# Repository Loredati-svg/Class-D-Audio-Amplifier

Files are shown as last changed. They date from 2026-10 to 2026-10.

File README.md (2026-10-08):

<h1 align="center">🔊 Class-D Stereo Audio Amplifier</h1>

<p align="center">
  
  
  
  
</p>

An open-source stereo **Class-D** audio amplifier with a **USB-C digital input**, analog **bass / treble tone control** and a **volume knob**, built around the Texas Instruments **TPA3116D2** and designed in **KiCad 10.0**.

Plug a phone or a PC into the USB-C port: the board shows up as a standard USB sound card (no drivers needed) and drives a pair of passive bookshelf speakers (4–8 Ω) from a single **24 V DC** supply.

---

> 🛠️ **Project Status: Active Development (v1)**
> The v1 schematic is being finalized; PCB layout comes next. Suggestions and feedback are welcome!

> 📶 **About Bluetooth**
> Bluetooth support is currently **on hold**. It will be reintegrated in a future hardware revision, once the v1 board (USB-C, without Bluetooth) has been built and validated.

---

## 📋 Table of Contents
- [Technical Specifications](#-technical-specifications)
- [Signal Chain](#-signal-chain)
- [Circuit Blocks](#-circuit-blocks)
- [Gain Structure](#-gain-structure)
- [Repository Structure](#-repository-structure)
- [Manufacturing](#-manufacturing)
- [Roadmap](#-roadmap)
- [License](#-license)

---

## ⚡ Technical Specifications

| Parameter | Value |
| :--- | :--- |
| **Supply voltage** | 24 V DC (3–5 A recommended), 5.5 × 2.1 mm barrel jack |
| **Audio input** | USB-C (USB 2.0 Full-Speed, USB Audio Class 1.0), 16-bit / up to 48 kHz |
| **DAC** | Texas Instruments **PCM2704C** |
| **Tone control** | Active Baxandall – bass and treble, about ±12 dB |
| **Amplifier IC** | Texas Instruments **TPA3116D2** (stereo BTL, Master mode, 26 dB) |
| **Output power** | ≈ 2 × 40 W into 4 Ω (clean), up to 2 × 50 W at 10 % THD |
| **Speaker load** | 4–8 Ω passive speakers |
| **Speaker outputs** | Phoenix Contact MKDS 1,5/2-5,08 screw terminals |
| **Controls** | Bass, Treble, Volume (dual-gang potentiometers) |
| **PCB** | 2 layers, FR-4, 1.6 mm, 1 oz copper |

---

## 🔗 Signal Chain

```mermaid
flowchart LR
    A[Phone / PC<br/>USB-C] --> B[PCM2704C<br/>USB Audio DAC]
    B --> C[Baxandall tone control<br/>OPA1678 · Bass / Treble]
    C --> D[Volume<br/>dual log pot]
    D --> E[TPA3116D2<br/>26 dB]
    E --> F[LC filter]
    F --> G[Speakers<br/>4–8 Ω]
```

---

## 🧩 Circuit Blocks

### USB-C input and DAC
- USB 2.0 Type-C receptacle with **5.1 kΩ** pull-downs on CC1/CC2 (device / UFP), so the phone acts as host and supplies VBUS
- **USBLC6-2SC6** ESD protection on D+, D− and VBUS
- **PCM2704C** bus-powered from VBUS: USB Audio Class 1.0, driverless on Android, iOS, Windows, macOS and Linux
- 12 MHz crystal, 22 Ω series resistors and 1.5 kΩ pull-up on D+
- AC-coupled line outputs (10 µF + 47 kΩ)

### Tone control
- Active **Baxandall** network (one per channel) around a TI **OPA1678** (dual, rail-to-rail output, low noise)
- **Bass:** shelf centred around ≈ 50 Hz, tuned for deep 808-style bass
- **Treble:** ≈ 8–10 kHz, mainly to tame harsh highs
- Unity gain with the knobs centred

### Volume
- Dual-gang **A10K** logarithmic potentiometer
- Placed **after** the tone stage, so it also attenuates op-amp noise at low listening levels

### Analog supply
- **L78L12** LDO: 24 V → 12 V for the op-amp
- **VREF = 6 V** virtual ground (100 kΩ / 100 kΩ divider + 10 µF) for single-supply operation

### Power amplifier (TPA3116D2)
- **Gain / mode:** 20 kΩ to GND and 100 kΩ to GVDD on `GAIN/SLV` → Master mode, 26 dB, 30 kΩ input impedance
- **Inputs:** single-ended, negative inputs AC-grounded through capacitors matching the positive ones (3.3 µF)
- **Modulation:** BD mode, 400 kHz switching, no power limit
- **PVCC decoupling:** 1 nF + 100 nF ceramic + 220 µF + 470 µF low-ESR bulk on each side of the IC
- **Output filter:** 10 µH / 680 nF LC filter + RC snubbers for EMI
- **Protection:** `FAULTZ` tied to `SDZ` for automatic recovery after a fault
- **Thermal:** the DAD package has its **PowerPAD on top**, so a heatsink must be mounted on the IC

### Anti-pop
- The PCM2704C `SSPND` signal (high when USB audio is active) drives a **2N7002** inverter on the TPA3116D2 `MUTE` pin
- RC network on `MUTE` (100 kΩ + 4.7 µF): unmute ≈ 1 s after the DAC becomes active, mute within ≈ 0.1 s when the phone is unplugged, slew rate within datasheet limits
- RC delay on `SDZ` (100 kΩ + 10 µF) keeps the amplifier in shutdown while the supplies settle at power-up

### Front-panel controls

| Knob | Part | Function |
| :--- | :--- | :--- |
| **Bass** | B100K dual-gang (RV1) | Low-frequency boost / cut |
| **Treble** | B100K dual-gang (RV2) | High-frequency boost / cut |
| **Volume** | A10K dual-gang (RV3) | Master volume |

---

## 📊 Gain Structure

The gain chain is chosen so that **full volume reaches maximum clean power without clipping**, and the op-amp keeps headroom even with the bass knob fully up.

| Stage | Gain | Level at full scale |
| :--- | :--- | :--- |
| PCM2704C output | – | 0.64 Vrms |
| Tone control (flat) | ×1 (0 dB) | 0.64 Vrms |
| Volume (max) | ×1 | 0.64 Vrms |
| TPA3116D2 | ×20 (26 dB) | ≈ 12.8 Vrms → ≈ 40 W into 4 Ω |

Worst case (full-scale track, +12 dB bass boost): the OPA1678 output swings ≈ 7.2 Vpp around 6 V, well inside its 12 V rail-to-rail range. If the amplifier clips, it happens **after** the volume knob, so turning the volume down removes it.

---

## 📁 Repository Structure

```
Class-D-Bluetooth-5.0-Stereo-Audio-Amplifier/
├── KiCad_Project/
│   ├── Audio_Amp_v1/          # v1 – USB-C DAC + tone control (schematic + PCB)
│   └── Fabrication_files/     # Gerber, drill, BOM and CPL (coming soon)
├── libs/                           # Project-specific symbols, footprints and 3D models
└── README.md
```

### Schematic sheets

| Sheet | Content |
| :--- | :--- |
| `USB_DAC` | USB-C, ESD protection, PCM2704C, crystal, L78L12, power input, speaker terminals, anti-pop driver |
| `Tone_Volume_control` | OPA1678, VREF, Baxandall networks (L/R), volume potentiometer |
| `Power_Amplifier` | TPA3116D2, gain setting, PVCC decoupling, LC output filter, EMI snubbers |

---

## 🏭 Manufacturing

The board is designed to be manufactured by **JLCPCB** and assembled by hand (stencil + hot plate / hot air for SMD parts, soldering iron for through-hole parts).

| Option | Value |
| :--- | :--- |
| Layers | 2 |
| Thickness | 1.6 mm |
| Copper | 1 oz |
| Gerber export | Protel extensions, no X2 attributes |
| Drill | Excellon, mm, PTH + NPTH merged |
| Stencil | Top side only |

---

## 🗺️ Roadmap

**v1 – USB-C DAC (current)**
- [x] USB-C input and PCM2704C DAC
- [x] Baxandall tone control and volume
- [x] TPA3116D2 power stage
- [x] Anti-pop circuit
- [ ] ERC and schematic review
- [ ] Tone control AC simulation (ngspice)
- [ ] PCB layout and DRC
- [ ] Fabrication, assembly and bring-up
- [ ] Measurements (frequency response, THD+N, noise)
- [ ] Enclosure and front panel

**Future**
- [ ] Bluetooth input (reintegrated once v1 is validated)

---

## 📜 License

This hardware project is released under the **CERN Open Hardware Licence Permissive v2 ([CERN-OHL-P v2](https://ohwr.org/cernohl))**.

<p align="center">Designed by <b>LOREDATI Circuits</b></p>

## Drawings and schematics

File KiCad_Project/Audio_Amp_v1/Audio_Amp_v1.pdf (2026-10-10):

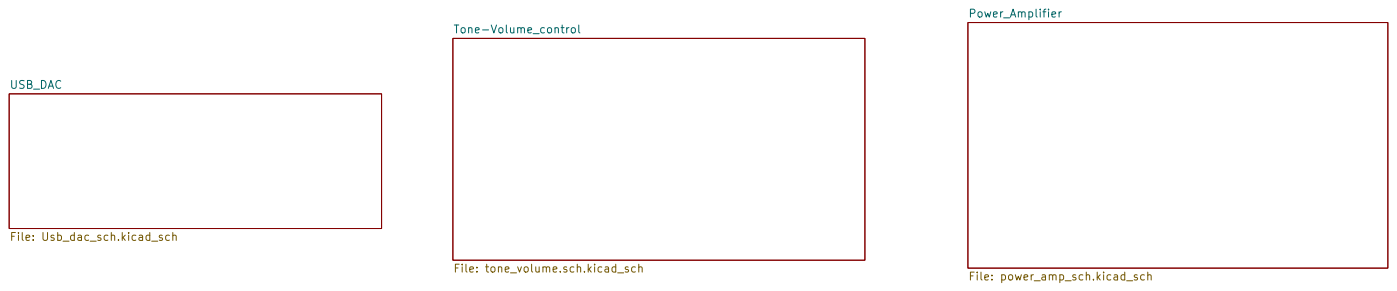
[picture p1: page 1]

Sheet: /
File: Audio_Amp_v1.kicad_sch
Title: Class-D Stereo Amplifier – USB-C v1

Size: A4 | Rev: v1
KiCad E.D.A. 10.0.5 | Id: 1/4

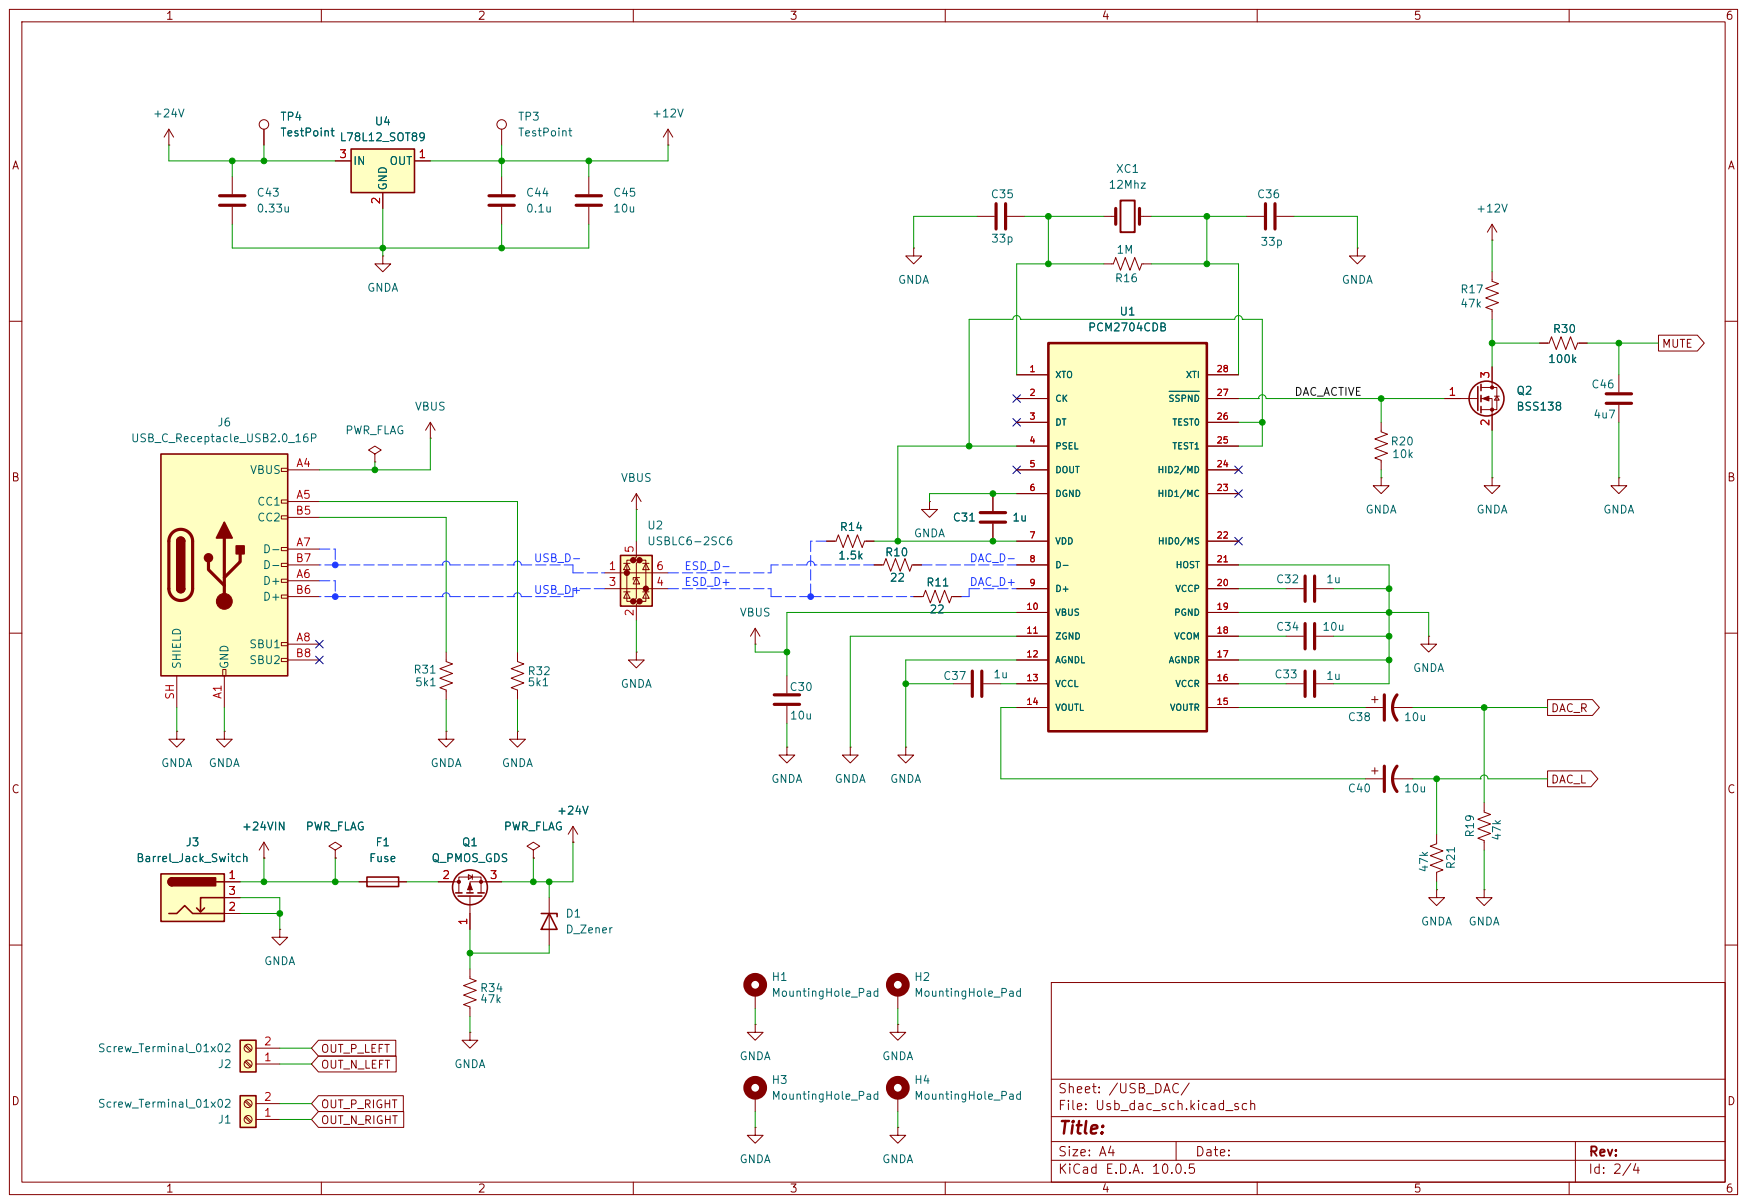
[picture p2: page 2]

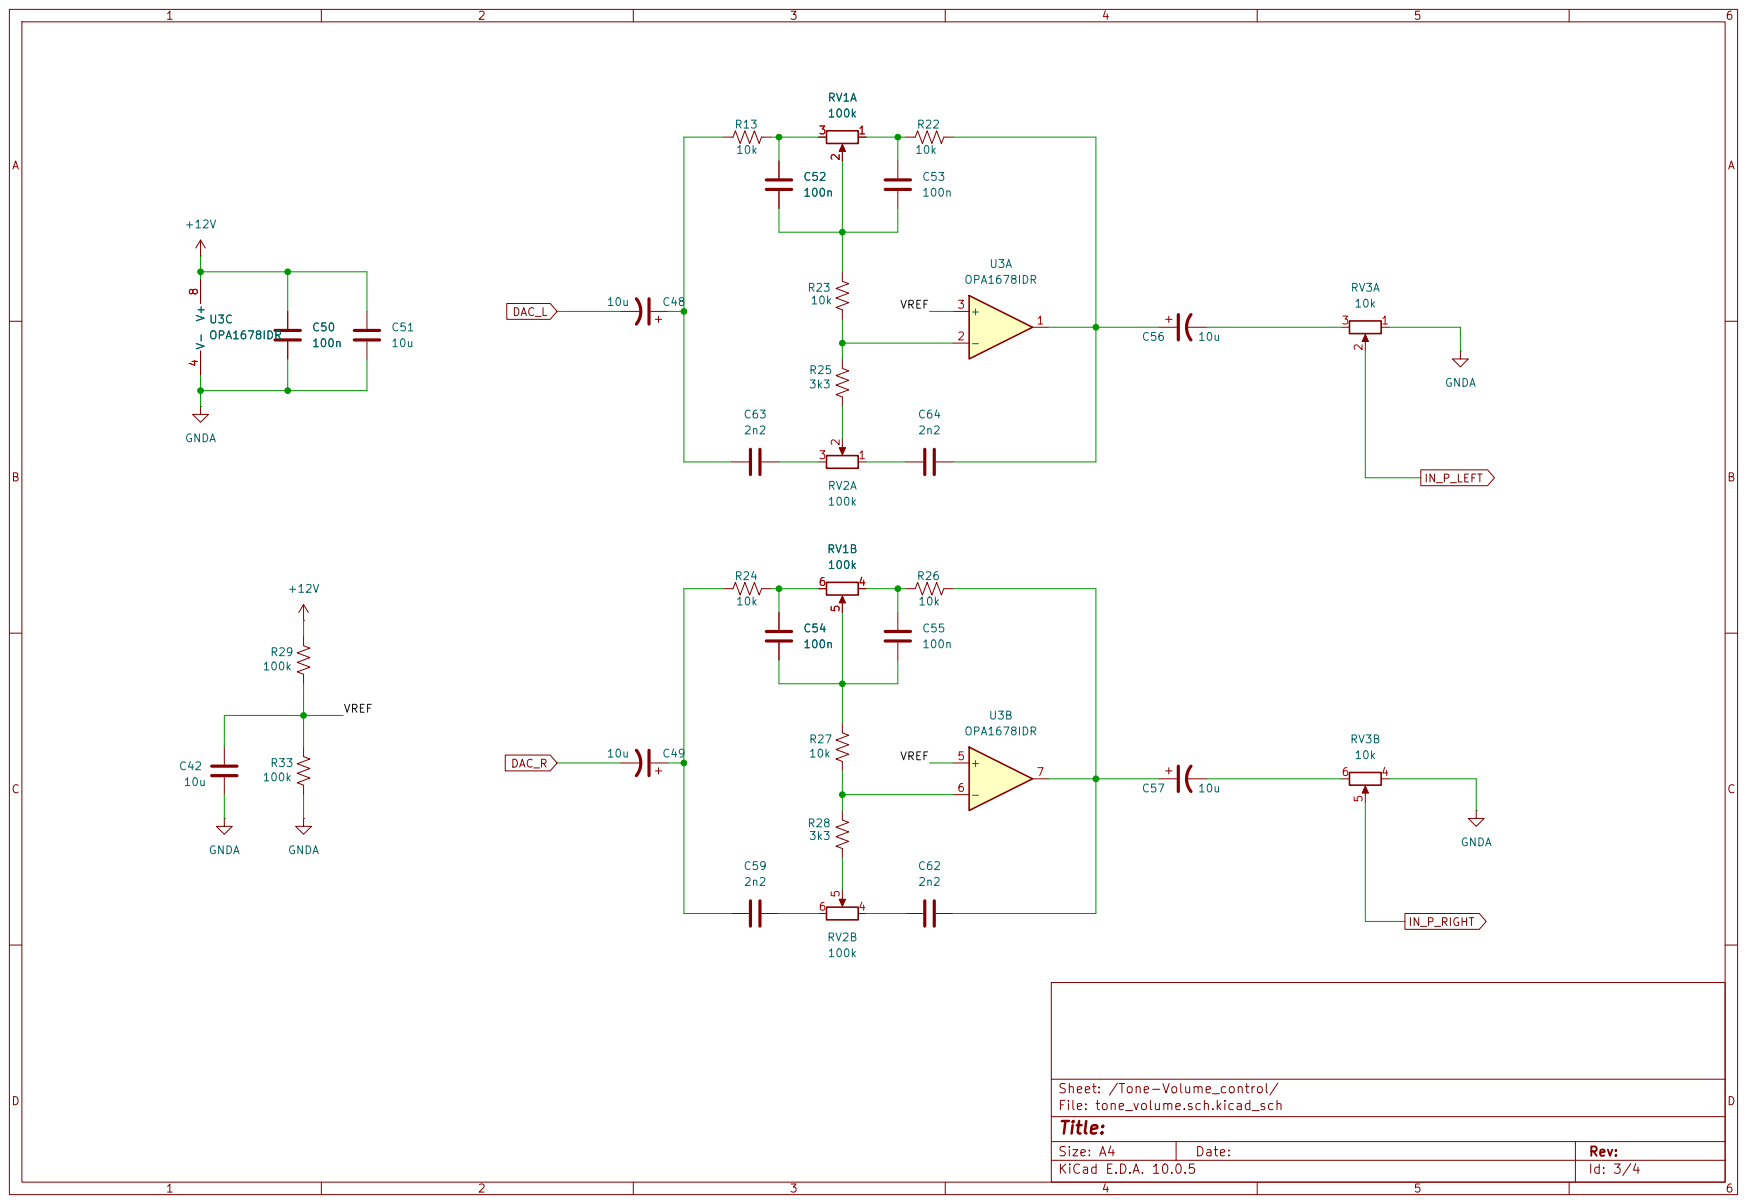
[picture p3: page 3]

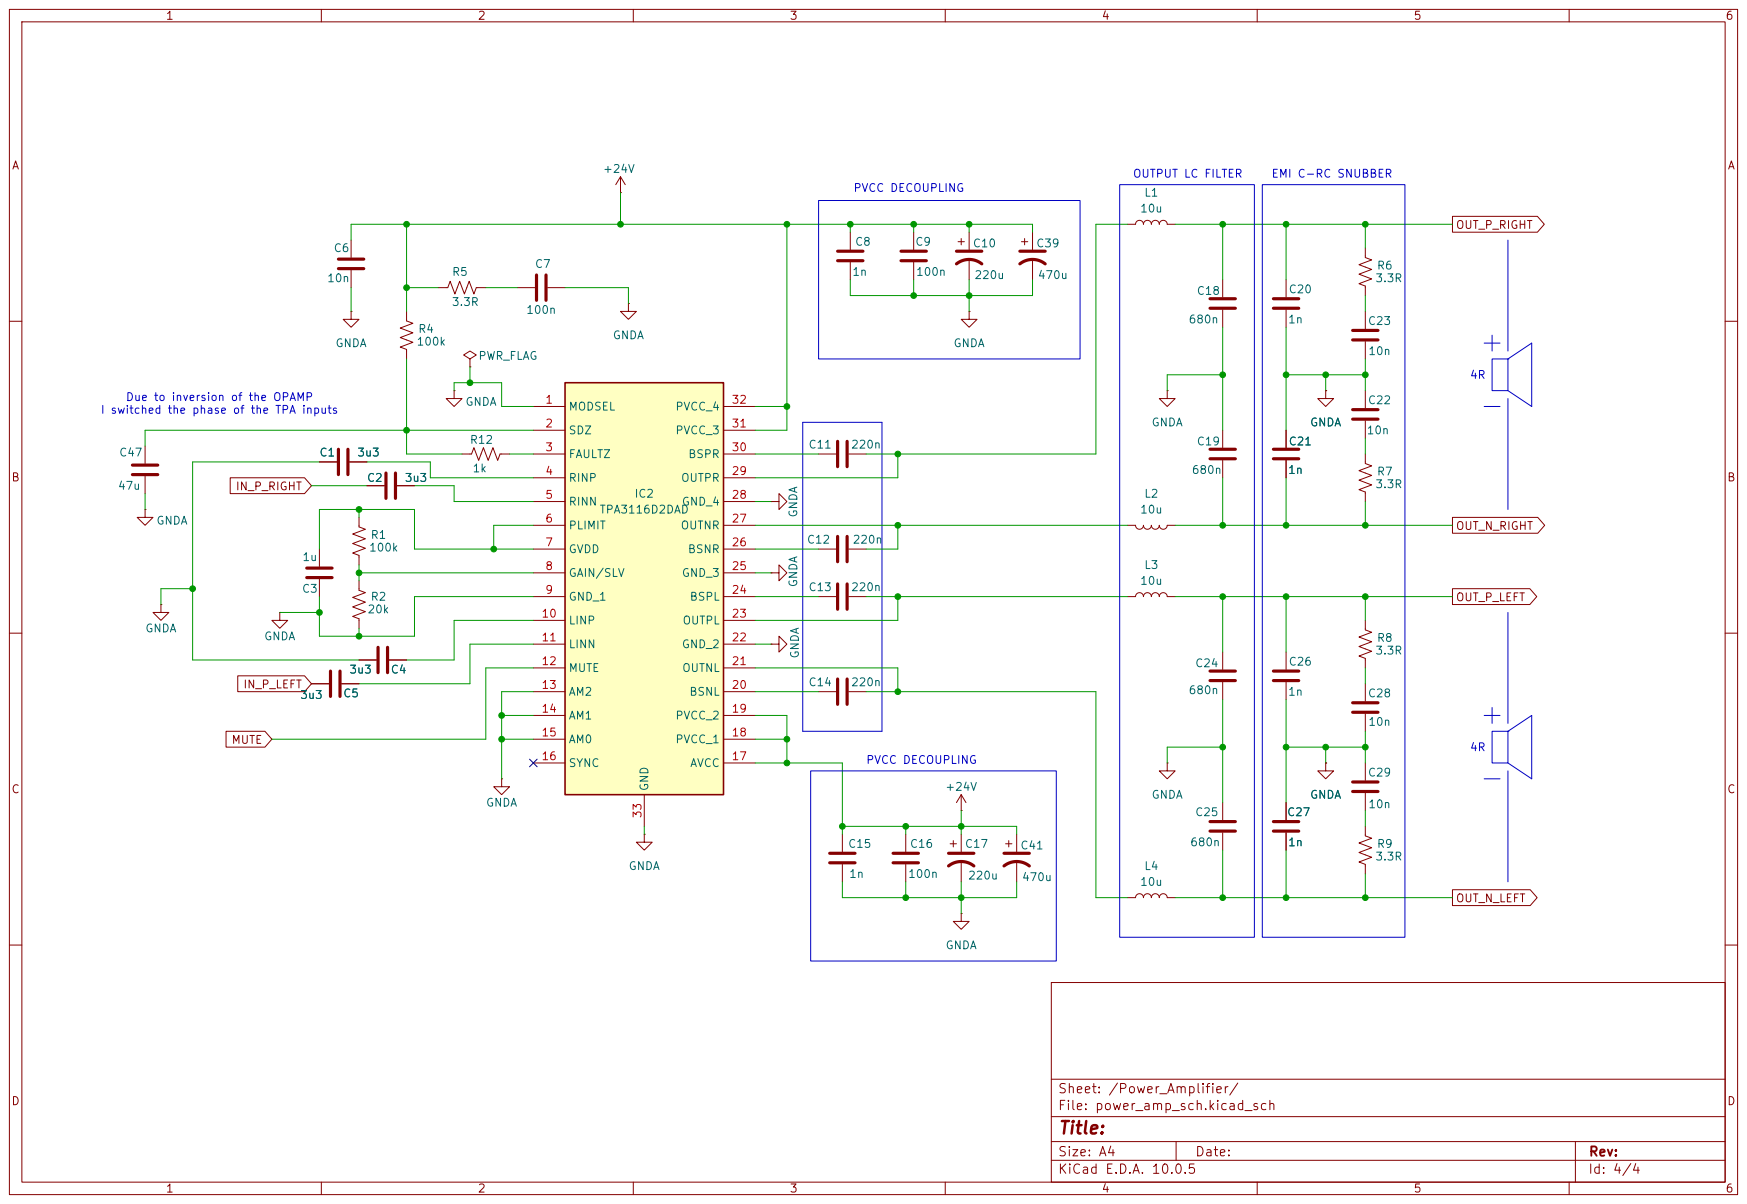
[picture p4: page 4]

Due to inversion of the OPAMP

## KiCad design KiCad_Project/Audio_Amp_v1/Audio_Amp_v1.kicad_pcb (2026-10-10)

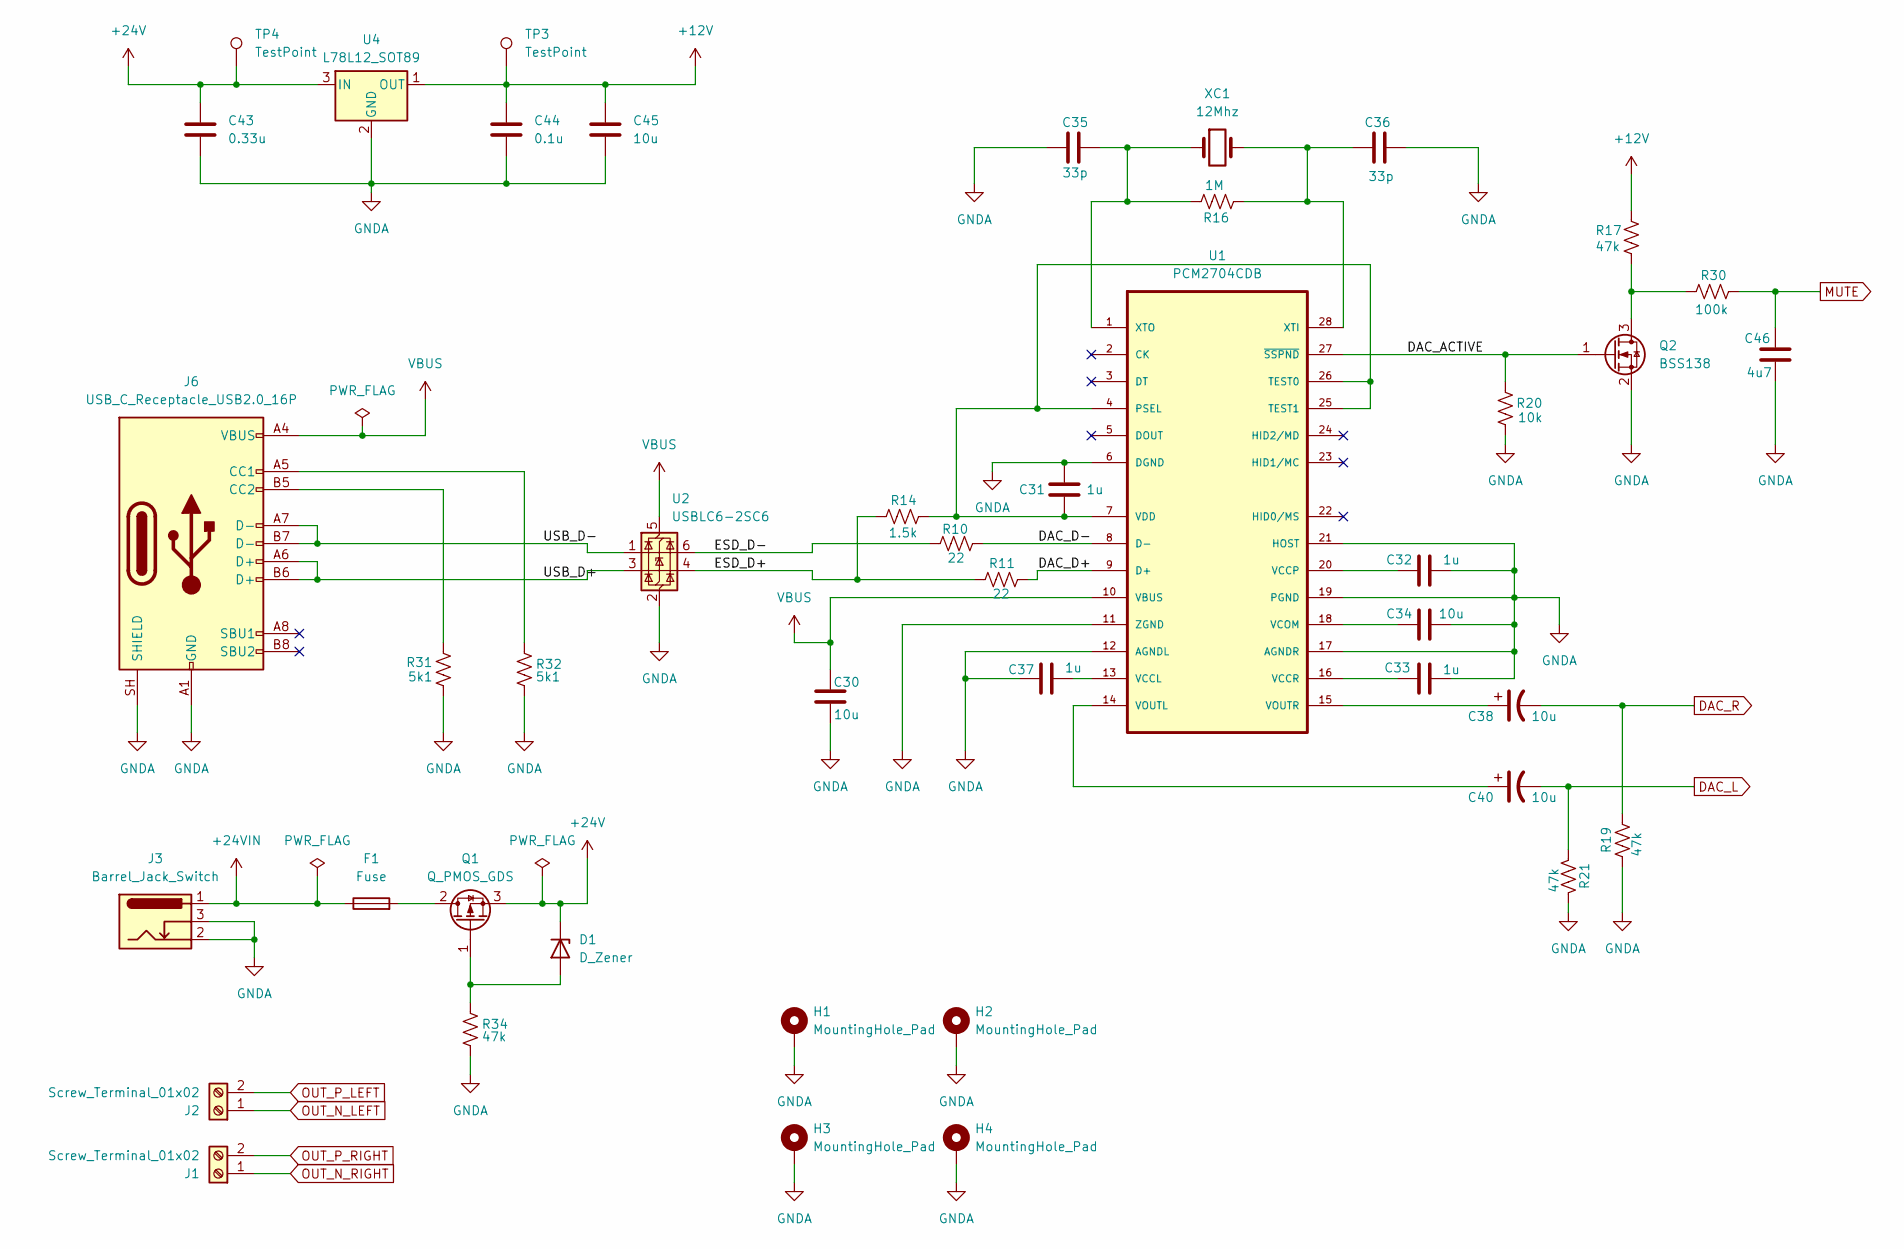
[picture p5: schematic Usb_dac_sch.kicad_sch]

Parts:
C30, C45: 10u; C_0805_2012Metric
C31: 1u; C_0603_1608Metric; LCSC C5199872
C32, C33, C37: 1u; C_0603_1608Metric
C34: 10u; C_0603_1608Metric
C35, C36: 33p; C_0603_1608Metric
C38, C40: 10u; CP_Elec_4x5.8; LCSC C116211
C43: 0.33u; C_0805
C44: 0.1u; C_0603_1608Metric
C46: 4u7; C_0805_2012Metric
D1: D_Zener; D_SOD-123
F1: Fuse; Fuse_2920_7451Metric_Pad2.10x5.45mm_HandSolder
H1, H2, H3, H4: MountingHole_Pad; MountingHole_3.2mm_M3_Pad_Via
J1, J2: Screw_Terminal_01x02; TerminalBlock_Phoenix_MKDS-1,5-2-5.08_1x02_P5.08mm_Horizont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
J3: Barrel_Jack_Switch; BarrelJack_CUI_PJ-102AH_Horizontal
J6: USB_C_Receptacle_USB2.0_16P; USB_C_Receptacle_GCT_USB4105-xx-A_16P_TopMnt_Horizontal
Q1: Q_PMOS_GDS; TO-252-2
Q2: BSS138; SOT-23
R10, R11: 22; R_0603_1608Metric; LCSC C25586
R14: 1.5k; R_0603_1608Metric; LCSC C25586
R16: 1M; R_0603_1608Metric
R17, R19, R21, R34: 47k; R_0603_1608Metric; LCSC C25586
R20: 10k; R_0603_1608Metric; LCSC C25586
R30: 100k; R_0603_1608Metric; LCSC C25586
R31, R32: 5k1; R_0603_1608Metric; LCSC C25586
TP3, TP4: TestPoint; TestPoint_Pad_D2.0mm
U1: PCM2704CDB; SOP65P780X200-28N
U2: USBLC6-2SC6; SOT-23-6
U4: L78L12_SOT89; SOT-89-3
XC1: 12Mhz; Crystal_SMD_HC49-SD; PARTNO ECS-120-20-5PX-TR

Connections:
+12V: C44.1, C45.1, R17.2, TP3.1 (1_1), U4.1 (OUT); also elsewhere on the board
+24V: C43.1, D1.1 (K), Q1.3 (S), TP4.1 (1_1), U4.3 (IN); also elsewhere on the board
+24VIN: F1.1, J3.1
/USB_DAC/DAC_ACTIVE: Q2.1 (G), R20.2, U1.27 (~SSPND)
/USB_DAC/DAC_D+: R11.2, U1.9 (D+)
/USB_DAC/DAC_D-: R10.2, U1.8 (D-)
/USB_DAC/ESD_D+: R11.1, R14.2, U2.4 (I/O2)
/USB_DAC/ESD_D-: R10.1, U2.6 (I/O1)
/USB_DAC/USB_D+: J6.A6 (D+), J6.B6 (D+), U2.3 (I/O2)
/USB_DAC/USB_D-: J6.A7 (D-), J6.B7 (D-), U2.1 (I/O1)
DAC_L: C40.2, R21.2; also elsewhere on the board
DAC_R: C38.2, R19.2; also elsewhere on the board
GNDA: C30.1, C31.2, C32.1, C33.1, C34.1, C35.1, C36.1, C37.2, C43.2, C44.2, C45.2, C46.2, H1.1 (1_1), H2.1 (1_1), H3.1 (1_1), H4.1 (1_1), J3.2, J3.3, J6.A1 (GND), J6.A12 (GND), J6.B1 (GND), J6.B12 (GND), J6.SH (SHIELD), Q2.2 (S), R19.1, R20.1, R21.1, R31.2, R32.2, R34.2, U1.6 (DGND), U1.11 (ZGND), U1.12 (AGNDL), U1.17 (AGNDR), U1.19 (PGND), U1.21 (HOST), U2.2 (GND), U4.2 (GND); also elsewhere on the board
MUTE: C46.1, R30.1; also elsewhere on the board
unnamed: D1.2 (A), Q1.1 (G), R34.1
unnamed: J6.A5 (CC1), R32.1
unnamed: J6.B5 (CC2), R31.1
unnamed: F1.2, Q1.2 (D)
unnamed: Q2.3 (D), R17.1, R30.2
unnamed: C31.1, R14.1, U1.4 (PSEL), U1.7 (VDD), U1.25 (TEST1), U1.26 (TEST0)
unnamed: C37.1, U1.13 (VCCL)
unnamed: C32.2, U1.20 (VCCP)
unnamed: C33.2, U1.16 (VCCR)
unnamed: C34.2, U1.18 (VCOM)
unnamed: C40.1, U1.14 (VOUTL)
unnamed: C38.1, U1.15 (VOUTR)
unnamed: C36.2, R16.2, U1.28 (XTI), XC1.2
unnamed: C35.2, R16.1, U1.1 (XTO), XC1.1
OUT_N_LEFT: J2.1; also elsewhere on the board
OUT_N_RIGHT: J1.1; also elsewhere on the board
OUT_P_LEFT: J2.2; also elsewhere on the board
OUT_P_RIGHT: J1.2; also elsewhere on the board
VBUS: C30.2, J6.A4 (VBUS), J6.A9 (VBUS), J6.B4 (VBUS), J6.B9 (VBUS), U1.10 (VBUS), U2.5 (VBUS)

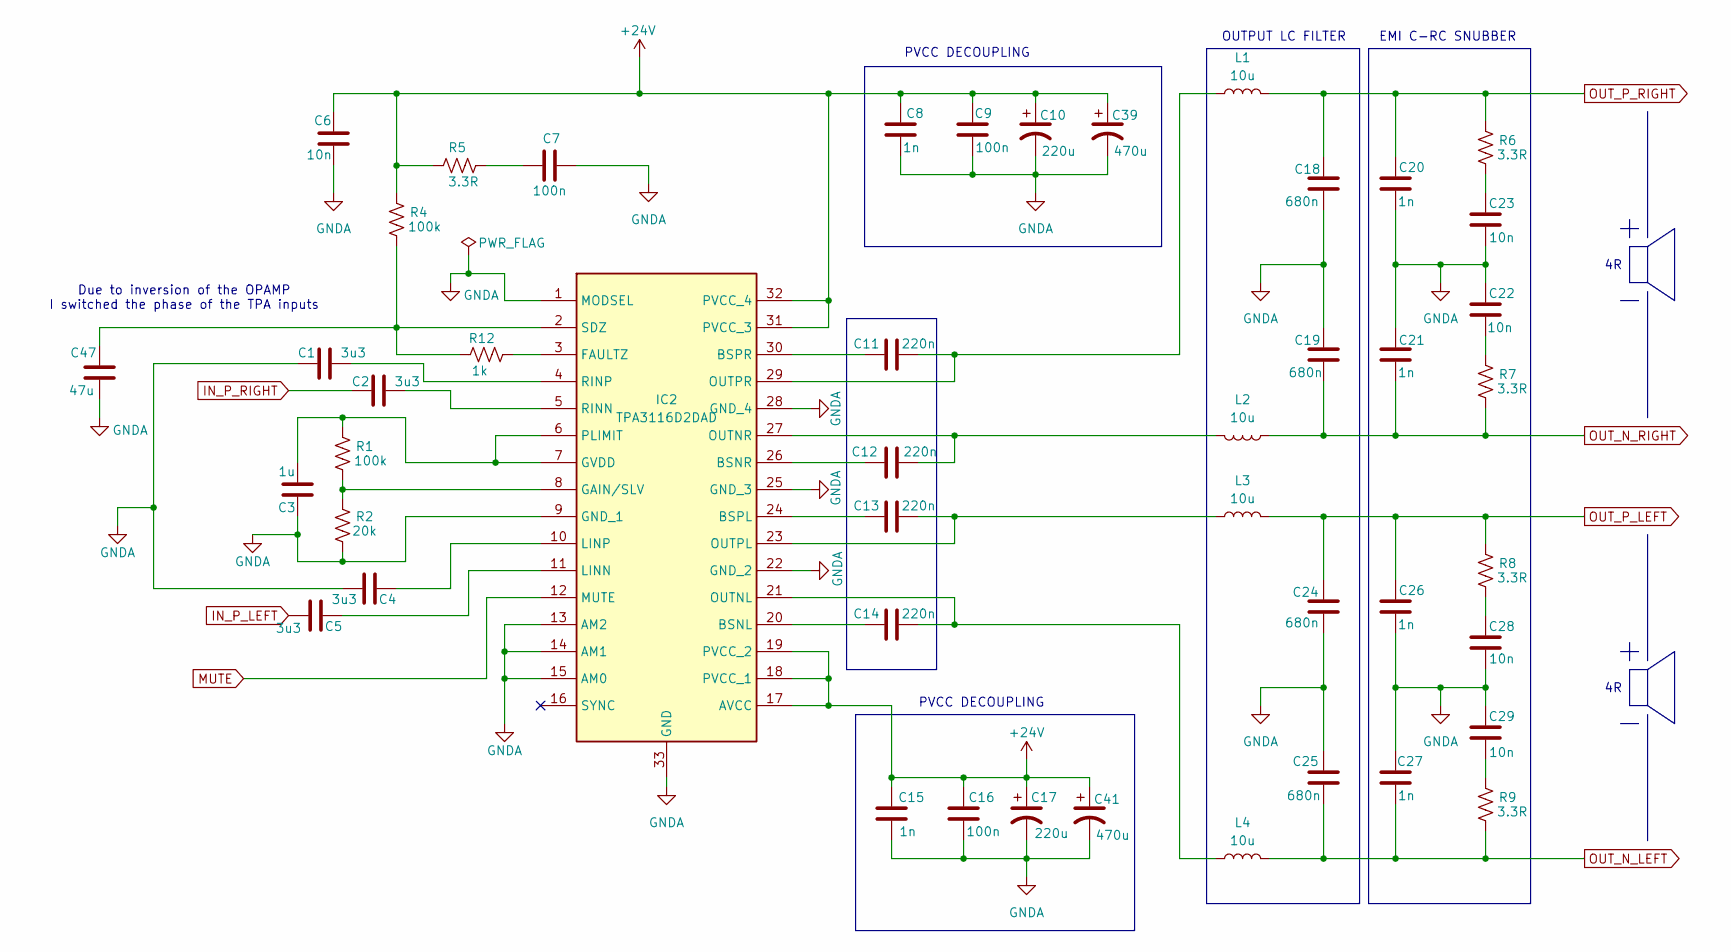
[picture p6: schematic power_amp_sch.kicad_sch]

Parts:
C1, C2, C4, C5: 3u3; C_0603_1608Metric; LCSC C5199872
C3: 1u; C_0603_1608Metric; LCSC C5199872
C6, C22, C23, C28, C29: 10n; C_0603_1608Metric; LCSC C100042
C7: 100n; C_0603_1608Metric; LCSC C1591
C8, C15: 1n; C_0805_2012Metric; LCSC C46653
C9, C16: 100n; C_0805_2012Metric; LCSC C49678
C10, C17: 220u; EEHZT1E561UV; LCSC C116211
C11, C12, C13, C14: 220n; C_0805_2012Metric; LCSC C5378
C18, C19, C24, C25: 680n; C_1206_3216Metric; LCSC C1881
C20, C21, C26, C27: 1n; C_0603_1608Metric; LCSC C100040
C39, C41: 470u; CP_Elec_10x10.5; LCSC EEE-FN1V471UL
C47: 47u; CP_Elec_6.3x5.9; LCSC EEE-FK1V470P
IC2: TPA3116D2DAD; SOP65P810X120-32N; Mouser Part Number 595-TPA3116D2DAD
L1, L2, L3, L4: 10u; INDPM8479X720N
R1, R4: 100k; R_0603_1608Metric; LCSC C2907088
R2: 20k; R_0603_1608Metric; LCSC C25586
R5, R6, R7, R8, R9: 3.3R; R_1206_3216Metric; LCSC C2907471
R12: 1k; R_0603_1608Metric; LCSC C2907088

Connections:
+24V: C6.2, C8.1, C9.1, C10.1, C15.1, C16.1, C17.1, C39.1, C41.1, IC2.17 (AVCC), IC2.18 (PVCC_1), IC2.19 (PVCC_2), IC2.31 (PVCC_3), IC2.32 (PVCC_4), R4.1, R5.1; also elsewhere on the board
GNDA: C1.1, C3.1, C4.2, C6.1, C7.1, C8.2, C9.2, C10.2, C15.2, C16.2, C17.2, C18.2, C19.1, C20.2, C21.1, C22.1, C23.2, C24.2, C25.1, C26.2, C27.1, C28.2, C29.1, C39.2, C41.2, C47.1, IC2.1 (MODSEL), IC2.9 (GND_1), IC2.13 (AM2), IC2.14 (AM1), IC2.15 (AM0), IC2.22 (GND_2), IC2.25 (GND_3), IC2.28 (GND_4), IC2.33 (GND), R2.2; also elsewhere on the board
IN_P_LEFT: C5.2; also elsewhere on the board
IN_P_RIGHT: C2.1; also elsewhere on the board
MUTE: IC2.12 (MUTE); also elsewhere on the board
unnamed: C7.2, R5.2
unnamed: C22.2, R7.1
unnamed: C23.1, R6.2
unnamed: C28.1, R8.2
unnamed: C29.2, R9.1
unnamed: C14.1, IC2.20 (BSNL)
unnamed: C12.1, IC2.26 (BSNR)
unnamed: C13.1, IC2.24 (BSPL)
unnamed: C11.1, IC2.30 (BSPR)
unnamed: IC2.3 (FAULTZ), R12.2
unnamed: IC2.8 (GAIN/SLV), R1.2, R2.1
unnamed: C3.2, IC2.6 (PLIMIT), IC2.7 (GVDD), R1.1
unnamed: C5.1, IC2.11 (LINN)
unnamed: C4.1, IC2.10 (LINP)
unnamed: C14.2, IC2.21 (OUTNL), L4.1
unnamed: C12.2, IC2.27 (OUTNR), L2.2
unnamed: C13.2, IC2.23 (OUTPL), L3.1
unnamed: C11.2, IC2.29 (OUTPR), L1.1
unnamed: C2.2, IC2.5 (RINN)
unnamed: C1.2, IC2.4 (RINP)
unnamed: C47.2, IC2.2 (SDZ), R4.2, R12.1
OUT_N_LEFT: C25.2, C27.2, L4.2, R9.2; also elsewhere on the board
OUT_N_RIGHT: C19.2, C21.2, L2.1, R7.2; also elsewhere on the board
OUT_P_LEFT: C24.1, C26.1, L3.2, R8.1; also elsewhere on the board
OUT_P_RIGHT: C18.1, C20.1, L1.2, R6.1; also elsewhere on the board

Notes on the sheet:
Due to inversion of the OPAMP I switched the phase of the TPA inputs
PVCC DECOUPLING
OUTPUT LC FILTER
EMI C-RC SNUBBER

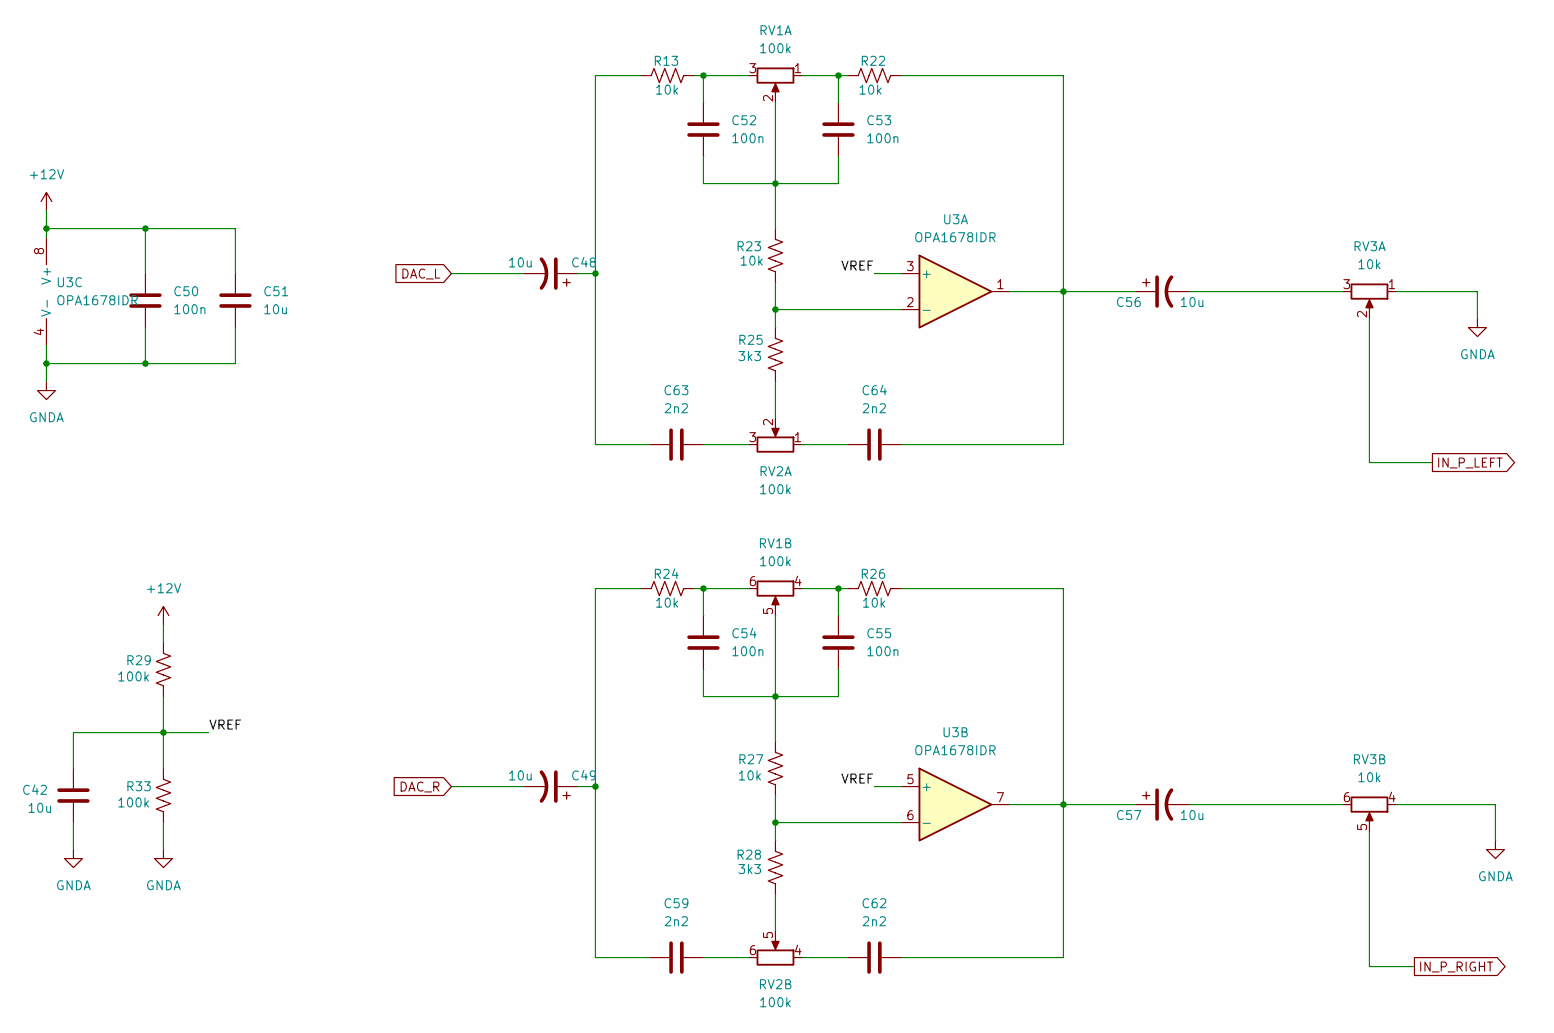
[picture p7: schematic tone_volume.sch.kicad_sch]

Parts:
C42, C51: 10u; C_0805_2012Metric
C48, C49, C56, C57: 10u; CP_Elec_4x5.8; LCSC C116211
C50: 100n; C_0603_1608Metric
C52, C53, C54, C55: 100n; C_1206_3216Metric
C59, C62, C63, C64: 2n2; C_0603_1608Metric
R13, R22, R23, R24, R26, R27: 10k; R_0603_1608Metric; LCSC C25586
R25, R28: 3k3; R_0603_1608Metric; LCSC C25586
R29, R33: 100k; R_0603_1608Metric; LCSC C25586
RV1, RV2: 100k; Potentiometer_Alps_RK09L_Double_Horizontal; PARTNO RK09L1220A1
RV3: 10k; Potentiometer_Alps_RK097_Dual_Horizontal; PARTNO RKRK09712200HA
U3: OPA1678IDR; SOIC-8_3.9x4.9mm_P1.27mm

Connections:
+12V: C50.1, C51.1, R29.2, U3.8 (V+); also elsewhere on the board
/Tone-Volume_control/VREF: C42.1, R29.1, R33.2, U3.3 (+), U3.5 (+)
DAC_L: C48.2; also elsewhere on the board
DAC_R: C49.2; also elsewhere on the board
GNDA: C42.2, C50.2, C51.2, R33.1, RV1.MP (GNDA), RV2.MP (GNDA), RV3.1, RV3.4, U3.4 (V-); also elsewhere on the board
IN_P_LEFT: RV3.2; also elsewhere on the board
IN_P_RIGHT: RV3.5; also elsewhere on the board
unnamed: C48.1, C63.2, R13.1
unnamed: C49.1, C59.2, R24.1
unnamed: C52.1, C53.1, R23.2, RV1.2
unnamed: C52.2, R13.2, RV1.3
unnamed: C53.2, R22.1, RV1.1
unnamed: C54.1, C55.1, R27.2, RV1.5
unnamed: C54.2, R24.2, RV1.6
unnamed: C55.2, R26.1, RV1.4
unnamed: C56.1, C64.1, R22.2, U3.1
unnamed: C56.2, RV3.3
unnamed: C57.1, C62.1, R26.2, U3.7
unnamed: C57.2, RV3.6
unnamed: C59.1, RV2.6
unnamed: C62.2, RV2.4
unnamed: C63.1, RV2.3
unnamed: C64.2, RV2.1
unnamed: R25.1, RV2.2
unnamed: R28.1, RV2.5
unnamed: R23.1, R25.2, U3.2 (-)
unnamed: R27.1, R28.2, U3.6 (-)

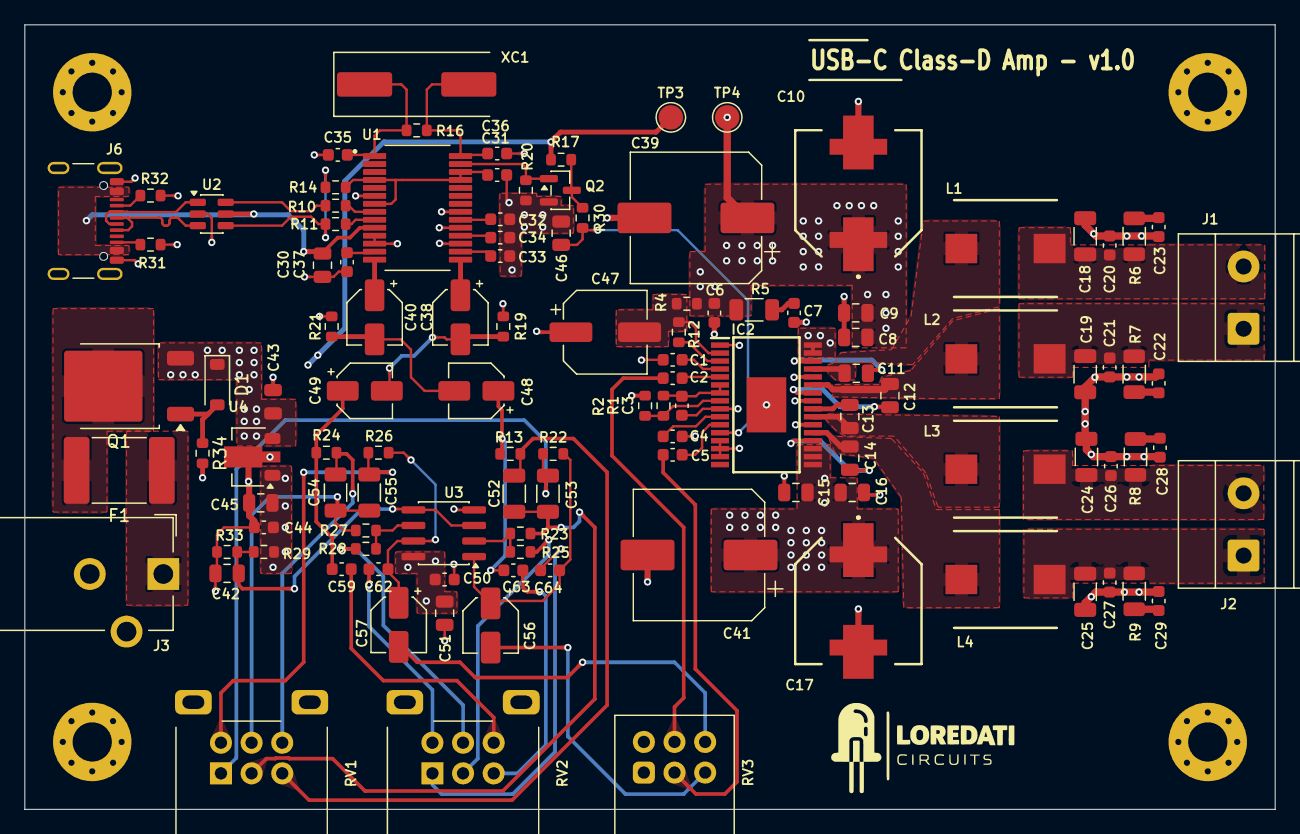
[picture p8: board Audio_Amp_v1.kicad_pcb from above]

Board: 4 copper layers, 102.0 x 64.0 mm, 119 parts (0 on the bottom side), 77 nets.

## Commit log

2026-09-26 Updated readme
    Added PCB layout section with an image.
2026-09-26 Added name on PCB
    [Audio_Amp_v1.kicad_pcb]
2026-10-01 added logo
    [Audio_Amp_v1.kicad_pcb]
2026-10-08 DRC clean and layout fix
    [Audio_Amp_v1.kicad_pcb]
2026-10-08 added gerber files, csv and BOM_pos
    [01_Power_Management.kicad_sch, 02_Bluetooth_Receiver.kicad_sch, 05_Power_Amplifier.kicad_sch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]
2026-10-08 Rinomina Audio_Amp_v1 in Audio_Amp_BT
    [01_Power_Management.kicad_sch, 02_Bluetooth_Receiver.kicad_sch, 03_Audio_DAC.kicad_sch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]
2026-10-08 Revise README for project updates and details
    Updated README to reflect changes in project status, KiCad version, and technical specifications.
2026-10-08 v1 USB-C DAC version, Bluetooth design moved to Audio_Amp_BT, new libs
    [Audio_Amp_v1-B_Cu.gbl, Audio_Amp_v1-B_Mask.gbs, Audio_Amp_v1-B_Paste.gbp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]
2026-10-08 schematic update
    [power_amp_sch.kicad_sch, tone_volume.sch.kicad_sch]
2026-10-08 added pdf schematic
2026-10-09 Started routing
    [Audio_Amp_v1.kicad_pcb, Usb_dac_sch.kicad_sch, power_amp_sch.kicad_sch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]
2026-10-09 layout finished
    [Audio_Amp_v1.kicad_pcb]
2026-10-10 added reverse polarity protection
    [Audio_Amp_v1.kicad_pcb, Usb_dac_sch.kicad_sch, power_amp_sch.kicad_sch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]
2026-10-11 Added led into pcb and lyout completed
2026-10-11 file gerber updated
2026-10-11 PCB completed
2026-10-11 Update PCB details from 2 layers to 4 layers
2026-10-11 Change PCB layer count from 2 to 4
    Updated the PCB layer count from 2 to 4.
2026-10-19 added Images folder and changed some relative paths in the Kicad preferences
2026-10-20 Use shared Kicad_Libs instead of project-specific libraries
    - Project parts moved to Kicad_Libs (symbol, footprint, 3D, datasheet)
    - Lib tables point to ${KIPRJMOD}/../KiCad_Libs (link via bring_libs.bat)
    - Schematic/PCB references (lib ids, footprints, 3D paths, datasheets)
    updated to the Kicad_Libs libraries; no design changes
    - Removed the old project-specific library folder
2026-10-22 Update README with library usage instructions
    Added instructions for using shared KiCad libraries.

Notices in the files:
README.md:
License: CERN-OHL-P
